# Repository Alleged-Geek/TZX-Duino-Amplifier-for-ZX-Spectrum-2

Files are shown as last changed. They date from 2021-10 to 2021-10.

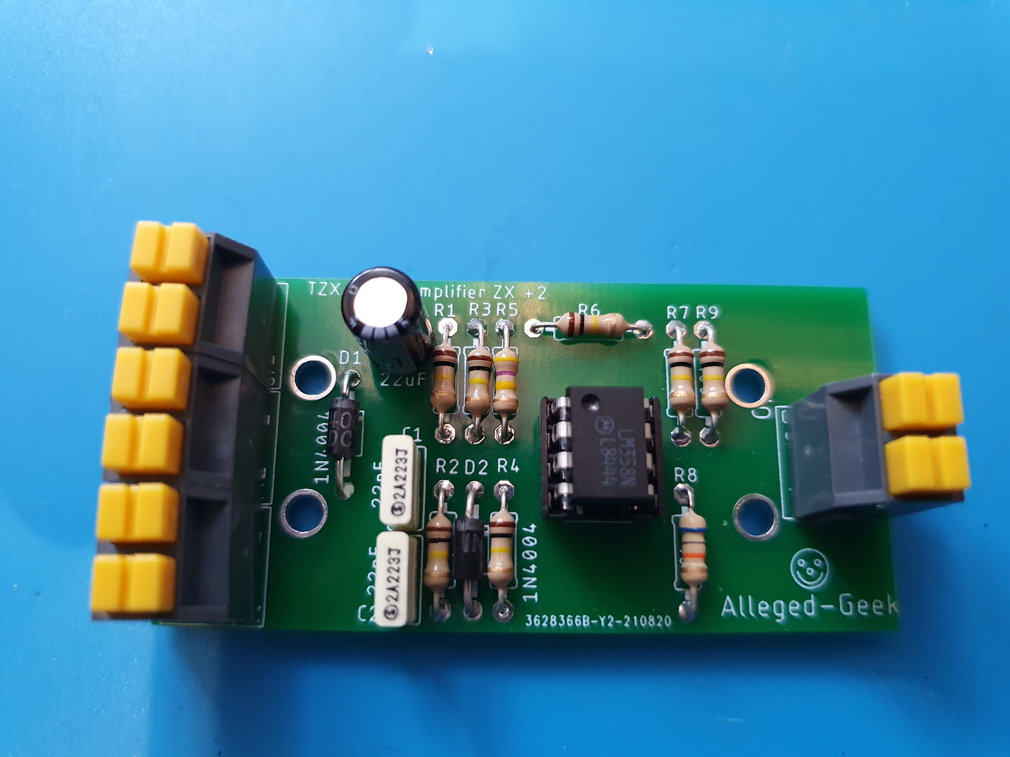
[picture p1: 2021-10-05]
2-045-complete.jpg

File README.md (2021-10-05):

# TZX-Duino-Amplifier-for-ZX-Spectrum-2

This is a PCB design of an amplifier which will allow you to use a TZX Duino with a ZX Spectrum +2

Included in this repositry are the following

Gerber Files in a Zip format which can be used if you decide to get the PCB's manufactured from PCB manufacturers such as JLPCB

Eagle Brd and SCH files should you wish to modify the PCB layout in any way

A parts list which has order codes and prices from www.rapidonline.com (although as shipping is quite high from them you may find it cheaper to buy from ebay or Amazon)
the partslist and order codes will give you the actual components I used which should make it easier to find on other sites. As the minimum order for a PCB from JLPCB is 5 PCB's the parts list contains enough components for 5 fully populated PCB's

Images of the PCB layouts and schematics

I will be updating my blog with the instllaton of this PCB

check out

alleged-geek.blogspot.com for further information

I hope that you find this useful

Any questions or comments greatly appreciated

Best regards,

Alleged-Geek

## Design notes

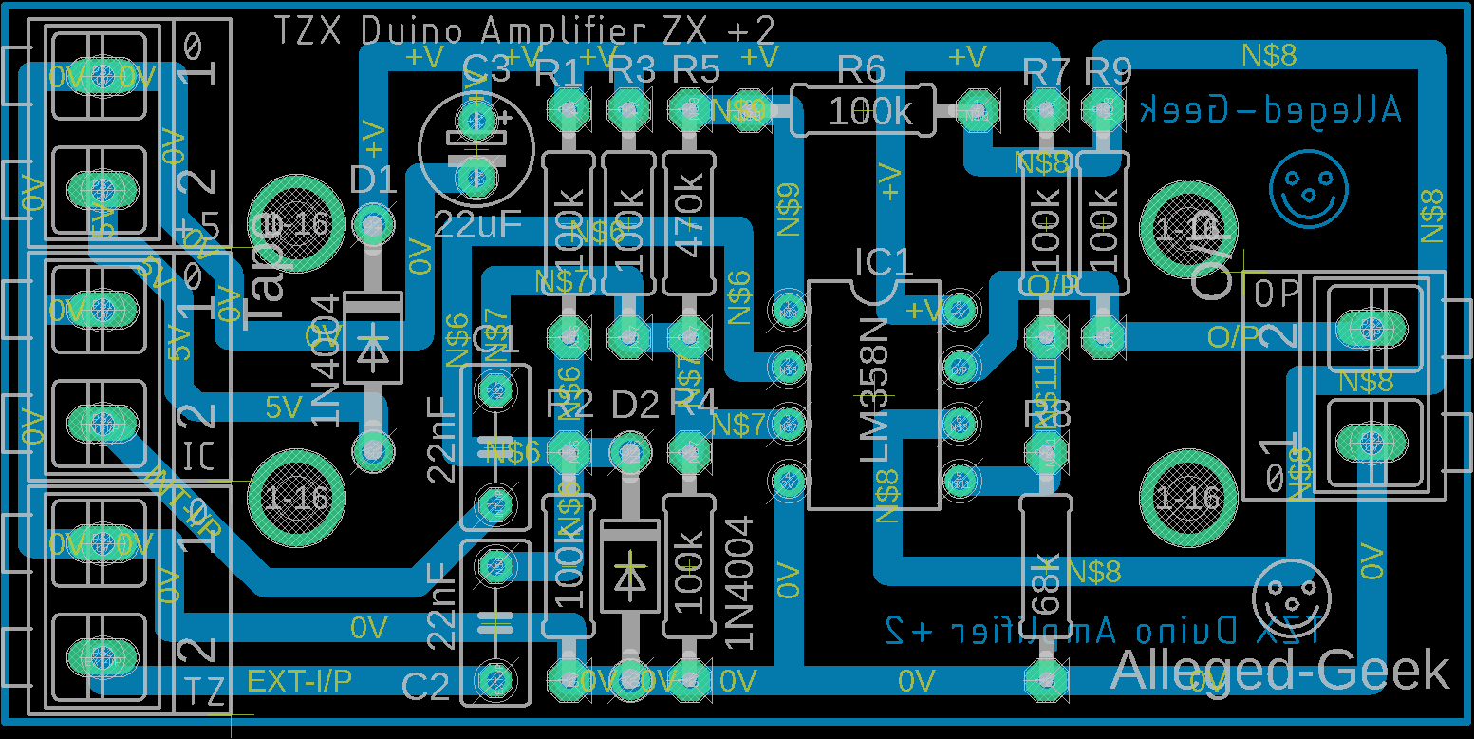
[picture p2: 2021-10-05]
ZX Plus 2 TZX Amplifier-BRD.bmp

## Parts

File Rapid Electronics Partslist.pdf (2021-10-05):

Order Code | Quantity | Product Description | Unit Price | Line Total
22-1720 | 5 | TruConnect 8 Pin 0.3in Turned Pin Socket | £0.31 | £1.56
62-0418 | 1 | TruOhm CR-025 100K Carbon Film Resistor 0.25W - Pack of 100 | £0.86 | £0.86
62-0414 | 1 | TruOhm CR-025 68K Carbon Film Resistor 0.25W - Pack of 100 | £0.86 | £0.86
62-0434 | 1 | TruOhm CR-025 470K Carbon Film Resistor 0.25W - Pack of 100 | £0.86 | £0.86
08-0307 | 10 | 0.022uF 5% 100V 5mm Pitch Faratronic Polyester Film Capacitor | £0.08 | £0.84
11-0810 | 5 | Forever 22uF 20% 10V 85°C 7mm Micro Miniature Radial Aluminium Electrolytic | £0.05 | £0.27
47-3142 | 20 | DC Components 1N4007 1A 1000V Silicon Rectifier Diode | £0.04 | £0.80
82-0332 | 5 | Texas Instruments LM358AP Low Power Dual OP Amp | £0.47 | £2.36
21-1560 | 5 | CamdenBoss CTB1500/2 2 Pole Commercial Standard Profile Screw Terminal 5mm | £0.16 | £0.78
21-1575 | 5 | CamdenBoss CTB1500/6 6 Pole Commercial Standard Profile Screw Terminal 5mm | £0.34 | £1.69

£10.88

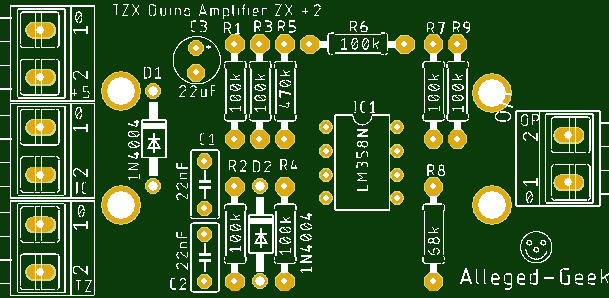
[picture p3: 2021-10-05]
ZX plus 2 TZX Amplifier-Component Side.jpg

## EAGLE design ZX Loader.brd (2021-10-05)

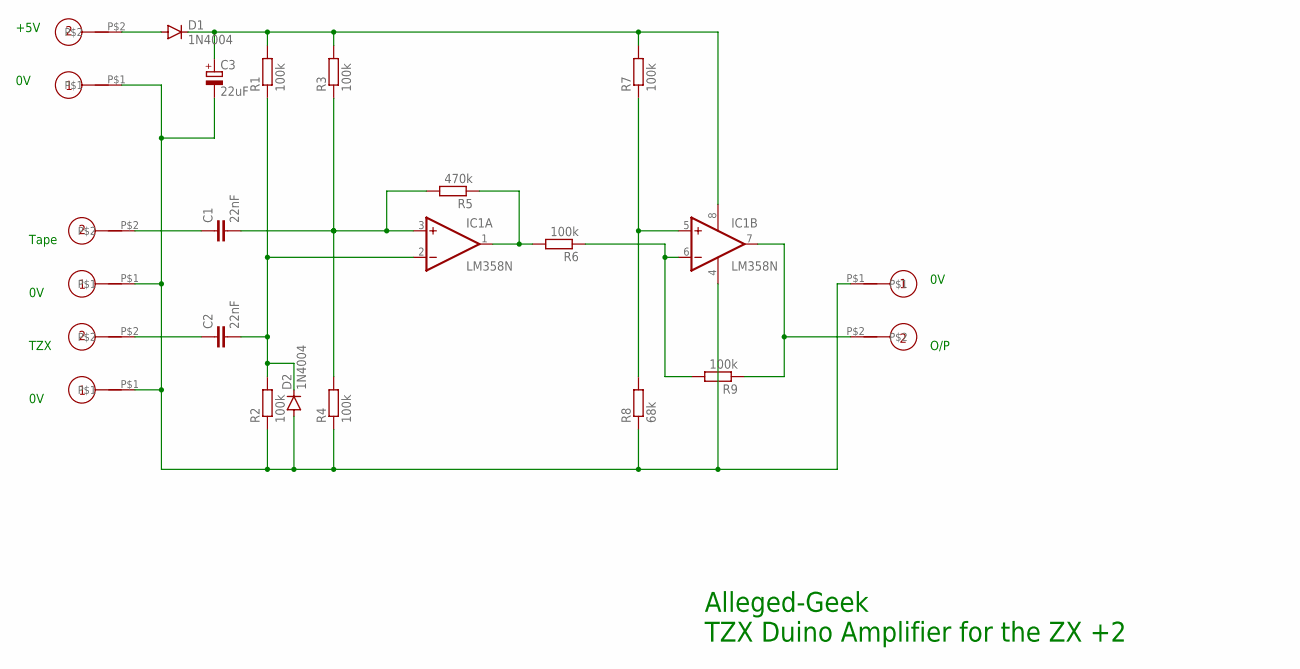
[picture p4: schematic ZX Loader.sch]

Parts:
C1, C2: 22nF; C050-030X075
C3: 22uF; E2,5-5
D1, D2: 1N4004; DO41-10
IC1: LM358N; DIL08
O/P: RGU-A2-PUSH-BUTTON-CONNECTOR; RGU-A2
POWER: Power; RGU-A2
R1, R2, R3, R4, R6, R7, R9: 100k; 0207/10
R5: 470k; 0207/10
R8: 68k; 0207/10
TZX: RGU-A2-PUSH-BUTTON-CONNECTOR; RGU-A2
U2: Tape; RGU-A2

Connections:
0V: C3.-, D2.A, IC1.4 (V-), O/P.P$1, POWER.P$1, R2.1, R4.1, R8.1, TZX.P$1, U2.P$1
5V: D1.A, POWER.P$2
+V: C3.+, D1.C, IC1.8 (V+), R1.2, R3.2, R7.2
EXT-I/P: C2.1, TZX.P$2
INT-I/P: C1.1, U2.P$2
unnamed: C2.2, D2.C, IC1.2 (-IN), R1.1, R2.2
unnamed: C1.2, IC1.3 (+IN), R3.1, R4.2, R5.2
unnamed: IC1.6 (-IN), R6.1, R9.2
unnamed: IC1.1 (OUT), R5.1, R6.2
unnamed: IC1.5 (+IN), R7.1, R8.2
O/P: IC1.7 (OUT), O/P.P$2, R9.1

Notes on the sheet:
+5V
O/P
TZX
Tape
Alleged-Geek TZX Duino Amplifier for the ZX +2

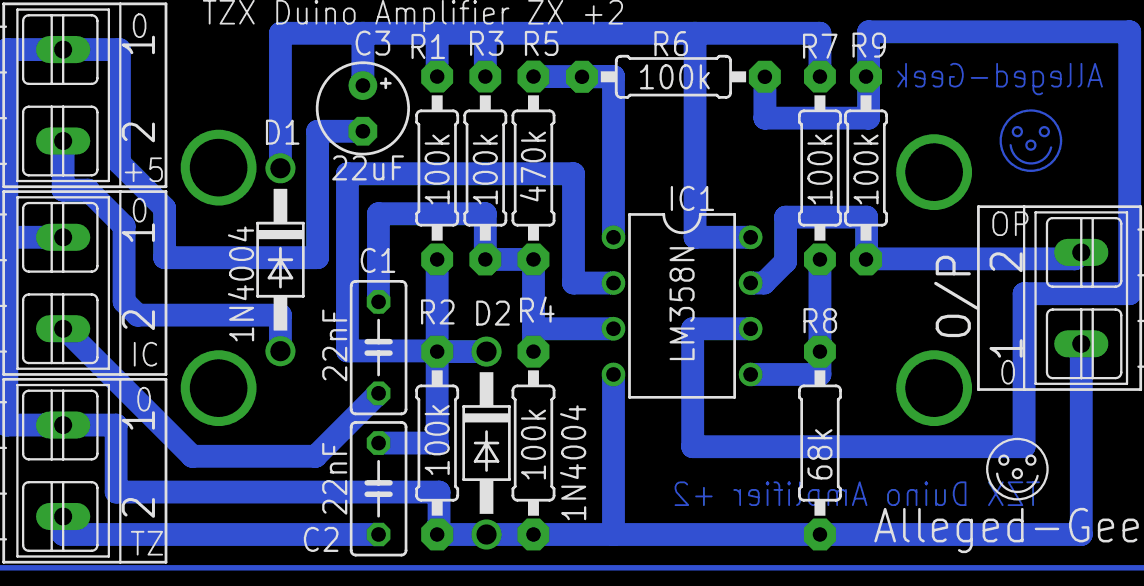
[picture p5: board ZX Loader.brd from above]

Board: 2 copper layers, 19 parts (0 on the bottom side), 11 nets.
